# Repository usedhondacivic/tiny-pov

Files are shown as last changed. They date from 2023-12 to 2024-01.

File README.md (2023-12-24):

# tiny-pov



Work in progress, check back soon for more.

[Checkout the GUI](http://michael-crum.com/tiny-pov/) for a sneak peak.

Tiny-pov is a low cost, high performance, persistence of vision display built with the STM32G0.
This project is designed to explore cost effective and easily manufacturable mechatronic design.

I currently plan to use a STM32G0 to relay data from a SD Card directly into a string of APA102 LEDs. The arm will be inductively powered using custom coils.

See my first revision of the POV display here: https://github.com/usedhondacivic/ECE-4760-POV-Display

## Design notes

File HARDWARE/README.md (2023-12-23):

# Hardware

The Tiny-pov circuit boards were designed using [SKiDL](https://devbisme.github.io/skidl/), a python library for generating KiCAD schematics from python code. 
The SKiDL source code for the PCBs is found in `arm_board.py` and `motor_board.py`. The KiCAD symbol and schematic libraries for all components is included, so it should run without any hassle.

```cd HARDWARE && python3 arm_board.py```

For power delivery, I designed a custom 3D printed inductive power coupling inspired by electric toothbrushes. It uses a core of [ferrous 3D printer filament](https://proto-pasta.com/products/magnetic-iron-pla) to increase the efficiency of transformer.
You can find the design files on [OnShape](https://cad.onshape.com/documents/c43b3a736df7726a49e53755/w/ad83221bbc41dda85aa40265/e/0c03297652a8e1a4c52ec09d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).

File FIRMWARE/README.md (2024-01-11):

# FIRMWARE

Tiny-pov's firmware is written in baremetal C without use of any libraries (including the c stdlib!). The project includeds a custom SPI, SD, APA102, and FAT32 drivers.

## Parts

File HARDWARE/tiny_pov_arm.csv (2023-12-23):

Id | Designator | Footprint | Quantity | Designation | Supplier and ref
1 | TP1,TP2,TP3,TP4,TP5 | TestPoint_Pad | 5 | TestPoint
2 | J1 | PinHeader_1x02 | 1 | Conn_01x02_Socket
3 | D13,D10,D46,D20,D7,D54,D9,D3,D57,D41,D60,D59,D25,D35,D33,D15,D49,D55,D48,D6,D4,D61,D52,D23,D56,D64,D39,D30,D18,D24,D32,D16,D40,D37,D45,D5,D44,D50,D34,D14,D43,D51,D21,D2,D28,D8,D1,D11,D26,D63,D36,D19,D27,D53,D38,D62,D12,D22,D42,D47,D31,D17,D58,D29 | LED-APA102-2020 | 64 | APA102-2020
4 | C4,C3 | C_0603_hand_solder | 2 | 22 uF
5 | R2,R3,R4 | R_0603_hand_solder | 3 | 47k
6 | JP1 | SolderJumper | 1 | SolderJumper_2_Open
7 | R1 | R_0603_hand_solder | 1 | 10k
8 | U3 | STM32_SO_8N | 1 | STM32G030J6Mx
9 | BR1 | DBF_DIO | 1 | DBF310-13
10 | C1 | C_polarized_TH | 1 | ? uF
11 | J2 | microSD | 1 | SdHolder
12 | U1 | TSOT-23-6_HandSoldering | 1 | AP63203WU
13 | C2,C6 | C_0603_hand_solder | 2 | 100 nF
14 | U2 | SC-59_Handsoldering | 1 | AH1806W
15 | C5 | C_polarized_TH | 1 | 100 uF
16 | L1 | L_0603_hand_solder | 1 | 6.8uH

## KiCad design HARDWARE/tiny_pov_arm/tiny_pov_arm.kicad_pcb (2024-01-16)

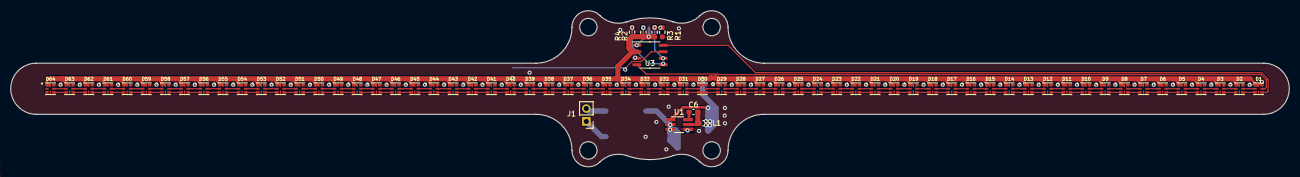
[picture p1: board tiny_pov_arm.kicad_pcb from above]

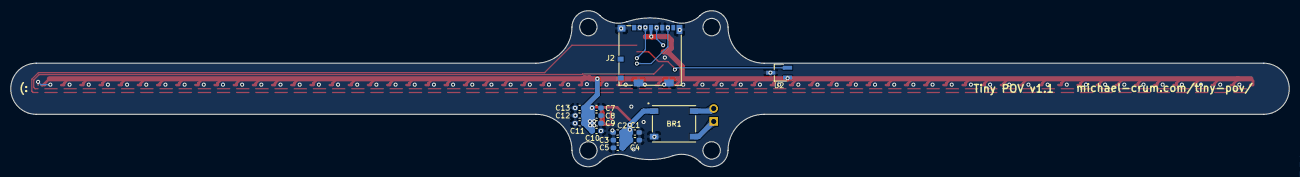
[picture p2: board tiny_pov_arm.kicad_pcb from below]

Board: 2 copper layers, 250.0 x 30.5 mm, 88 parts (15 on the bottom side), 140 nets.

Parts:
BR1: DBF310-13; DBF_DIO
C1, C2, C3, C4, C5, C7, C8, C9, C10, C11, C12, C13: 22 uF; C_0603_hand_solder
C6: 100 nF; C_0603_hand_solder
D1, D2, D3, D4, D5, D6, D7, D8, D9, D10, D11, D12, D13, D14, D15, D16, D17, D18, D19, D20, D21, D22, D23, D24, D25, D26, D27, D28, D29, D30, D31, D32, D33, D34, D35, D36, D37, D38, D39, D40, D41, D42, D43, D44, D45, D46, D47, D48, D49, D50, D51, D52, D53, D54, D55, D56, D57, D58, D59, D60, D61, D62, D63, D64: APA102-2020; LED_APA-102-2020-256-8
J1: Conn_01x02_Socket; PinHeader_1x02
J2: SdHolder; microSD
L1: 6.8uH; L_0603_hand_solder
R1: 10k; R_0603_hand_solder
R2, R3, R4: 47k; R_0603_hand_solder
U1: AP63203WU; TSOT-23-6_HandSoldering
U2: AH1806W; SC-59_Handsoldering
U3: STM32G030J6Mx; STM32_SO_8N

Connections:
BST: C6.1, U1.6
GND: BR1.3, C1.2, C2.2, C3.2, C4.2, C5.2, C7.2, C8.2, C9.2, C10.2, C11.2, C12.2, C13.2, D1.6, D2.6, D3.6, D4.6, D5.6, D6.6, D7.6, D8.6, D9.6, D10.6, D11.6, D12.6, D13.6, D14.6, D15.6, D16.6, D17.6, D18.6, D19.6, D20.6, D21.6, D22.6, D23.6, D24.6, D25.6, D26.6, D27.6, D28.6, D29.6, D30.6, D31.6, D32.6, D33.6, D34.6, D35.6, D36.6, D37.6, D38.6, D39.6, D40.6, D41.6, D42.6, D43.6, D44.6, D45.6, D46.6, D47.6, D48.6, D49.6, D50.6, D51.6, D52.6, D53.6, D54.6, D55.6, D56.6, D57.6, D58.6, D59.6, D60.6, D61.6, D62.6, D63.6, D64.6, J2.6, J2.11, R1.1, U1.4, U2.3, U3.3
HALL_DATA: U2.2, U3.7
LED_CLK: D1.5, U3.4
LED_DATA: D1.4, U3.8
SD_CS: J2.2, R1.2
SD_MISO: J2.7, R4.1, U3.5
SD_MOSI: J2.3, R3.1, U3.6
SD_SCK: J2.5, R2.1, U3.1
SW: C6.2, L1.1, U1.5
V_rect_plus: BR1.1, C1.1, C2.1, C3.1, C4.1, C5.1, U1.2, U1.3
Vac_a: BR1.4, J1.1
Vac_b: BR1.2, J1.2
Vdd: C7.1, C8.1, C9.1, C10.1, C11.1, C12.1, C13.1, D1.1, D2.1, D3.1, D4.1, D5.1, D6.1, D7.1, D8.1, D9.1, D10.1, D11.1, D12.1, D13.1, D14.1, D15.1, D16.1, D17.1, D18.1, D19.1, D20.1, D21.1, D22.1, D23.1, D24.1, D25.1, D26.1, D27.1, D28.1, D29.1, D30.1, D31.1, D32.1, D33.1, D34.1, D35.1, D36.1, D37.1, D38.1, D39.1, D40.1, D41.1, D42.1, D43.1, D44.1, D45.1, D46.1, D47.1, D48.1, D49.1, D50.1, D51.1, D52.1, D53.1, D54.1, D55.1, D56.1, D57.1, D58.1, D59.1, D60.1, D61.1, D62.1, D63.1, D64.1, J2.4, L1.2, R2.2, R3.2, R4.2, U1.1, U2.1, U3.2
apa_led_0_1_CK: D1.2, D2.5
apa_led_0_1_SD: D1.3, D2.4
apa_led_1_2_CK: D2.2, D3.5
apa_led_1_2_SD: D2.3, D3.4
apa_led_2_3_CK: D3.2, D4.5
apa_led_2_3_SD: D3.3, D4.4
apa_led_3_4_CK: D4.2, D5.5
apa_led_3_4_SD: D4.3, D5.4
apa_led_4_5_CK: D5.2, D6.5
apa_led_4_5_SD: D5.3, D6.4
apa_led_5_6_CK: D6.2, D7.5
apa_led_5_6_SD: D6.3, D7.4
apa_led_6_7_CK: D7.2, D8.5
apa_led_6_7_SD: D7.3, D8.4
apa_led_7_8_CK: D8.2, D9.5
apa_led_7_8_SD: D8.3, D9.4
apa_led_8_9_CK: D9.2, D10.5
apa_led_8_9_SD: D9.3, D10.4
apa_led_9_10_CK: D10.2, D11.5
apa_led_9_10_SD: D10.3, D11.4
apa_led_10_11_CK: D11.2, D12.5
apa_led_10_11_SD: D11.3, D12.4
apa_led_11_12_CK: D12.2, D13.5
apa_led_11_12_SD: D12.3, D13.4
apa_led_12_13_CK: D13.2, D14.5
apa_led_12_13_SD: D13.3, D14.4
apa_led_13_14_CK: D14.2, D15.5
apa_led_13_14_SD: D14.3, D15.4
apa_led_14_15_CK: D15.2, D16.5
apa_led_14_15_SD: D15.3, D16.4
apa_led_15_16_CK: D16.2, D17.5
apa_led_15_16_SD: D16.3, D17.4
apa_led_16_17_CK: D17.2, D18.5
apa_led_16_17_SD: D17.3, D18.4
apa_led_17_18_CK: D18.2, D19.5
apa_led_17_18_SD: D18.3, D19.4
apa_led_18_19_CK: D19.2, D20.5
apa_led_18_19_SD: D19.3, D20.4
apa_led_19_20_CK: D20.2, D21.5
apa_led_19_20_SD: D20.3, D21.4
apa_led_20_21_CK: D21.2, D22.5
apa_led_20_21_SD: D21.3, D22.4
apa_led_21_22_CK: D22.2, D23.5
apa_led_21_22_SD: D22.3, D23.4
apa_led_22_23_CK: D23.2, D24.5
apa_led_22_23_SD: D23.3, D24.4
apa_led_23_24_CK: D24.2, D25.5
apa_led_23_24_SD: D24.3, D25.4
apa_led_24_25_CK: D25.2, D26.5
apa_led_24_25_SD: D25.3, D26.4
apa_led_25_26_CK: D26.2, D27.5
apa_led_25_26_SD: D26.3, D27.4
apa_led_26_27_CK: D27.2, D28.5
apa_led_26_27_SD: D27.3, D28.4
apa_led_27_28_CK: D28.2, D29.5
apa_led_27_28_SD: D28.3, D29.4
apa_led_28_29_CK: D29.2, D30.5
apa_led_28_29_SD: D29.3, D30.4
apa_led_29_30_CK: D30.2, D31.5
apa_led_29_30_SD: D30.3, D31.4
apa_led_30_31_CK: D31.2, D32.5
apa_led_30_31_SD: D31.3, D32.4
apa_led_31_32_CK: D32.2, D33.5
apa_led_31_32_SD: D32.3, D33.4
apa_led_32_33_CK: D33.2, D34.5
apa_led_32_33_SD: D33.3, D34.4
apa_led_33_34_CK: D34.2, D35.5
apa_led_33_34_SD: D34.3, D35.4
apa_led_34_35_CK: D35.2, D36.5
apa_led_34_35_SD: D35.3, D36.4
apa_led_35_36_CK: D36.2, D37.5
apa_led_35_36_SD: D36.3, D37.4
apa_led_36_37_CK: D37.2, D38.5
apa_led_36_37_SD: D37.3, D38.4
apa_led_37_38_CK: D38.2, D39.5
apa_led_37_38_SD: D38.3, D39.4
apa_led_38_39_CK: D39.2, D40.5
apa_led_38_39_SD: D39.3, D40.4
apa_led_39_40_CK: D40.2, D41.5
apa_led_39_40_SD: D40.3, D41.4
apa_led_40_41_CK: D41.2, D42.5
apa_led_40_41_SD: D41.3, D42.4
apa_led_41_42_CK: D42.2, D43.5
apa_led_41_42_SD: D42.3, D43.4
apa_led_42_43_CK: D43.2, D44.5
apa_led_42_43_SD: D43.3, D44.4
apa_led_43_44_CK: D44.2, D45.5
apa_led_43_44_SD: D44.3, D45.4
apa_led_44_45_CK: D45.2, D46.5
apa_led_44_45_SD: D45.3, D46.4
apa_led_45_46_CK: D46.2, D47.5
apa_led_45_46_SD: D46.3, D47.4
apa_led_46_47_CK: D47.2, D48.5
apa_led_46_47_SD: D47.3, D48.4
apa_led_47_48_CK: D48.2, D49.5
apa_led_47_48_SD: D48.3, D49.4
apa_led_48_49_CK: D49.2, D50.5
apa_led_48_49_SD: D49.3, D50.4
apa_led_49_50_CK: D50.2, D51.5
apa_led_49_50_SD: D50.3, D51.4
apa_led_50_51_CK: D51.2, D52.5
apa_led_50_51_SD: D51.3, D52.4
apa_led_51_52_CK: D52.2, D53.5
apa_led_51_52_SD: D52.3, D53.4
apa_led_52_53_CK: D53.2, D54.5
apa_led_52_53_SD: D53.3, D54.4
apa_led_53_54_CK: D54.2, D55.5
apa_led_53_54_SD: D54.3, D55.4
apa_led_54_55_CK: D55.2, D56.5
apa_led_54_55_SD: D55.3, D56.4
apa_led_55_56_CK: D56.2, D57.5
apa_led_55_56_SD: D56.3, D57.4
apa_led_56_57_CK: D57.2, D58.5
apa_led_56_57_SD: D57.3, D58.4
apa_led_57_58_CK: D58.2, D59.5
apa_led_57_58_SD: D58.3, D59.4
apa_led_58_59_CK: D59.2, D60.5
apa_led_58_59_SD: D59.3, D60.4
apa_led_59_60_CK: D60.2, D61.5
apa_led_59_60_SD: D60.3, D61.4
apa_led_60_61_CK: D61.2, D62.5
apa_led_60_61_SD: D61.3, D62.4
apa_led_61_62_CK: D62.2, D63.5
apa_led_61_62_SD: D62.3, D63.4
apa_led_62_63_CK: D63.2, D64.5
apa_led_62_63_SD: D63.3, D64.4

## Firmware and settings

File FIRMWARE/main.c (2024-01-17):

/**
 * Author: Michael Crum
 * Date: 12/28/2023
 *
 * Entry point for Tiny POV
 *
 * https://github.com/usedhondacivic/tiny-pov
 * michael-crum.com/tiny-pov
 */

#include <stdbool.h>
#include <stdint.h>

#include "drivers/apa102/apa102.h"
#include "drivers/clock/clock.h"
#include "drivers/fat/fat.h"
#include "drivers/gpio/gpio.h"
#include "drivers/sd/sd.h"
#include "stm32g031xx.h"

static uint16_t sd_clk_pin = PIN('B', 8);
static uint16_t sd_mosi_pin = PIN('A', 10);
static uint16_t sd_miso_pin = PIN('A', 9);

static uint16_t apa102_clk_pin = PIN('A', 1);
static uint16_t apa102_data_pin = PIN('B', 5);

void apa102_gpio_map()
{
	// disable SWD
	gpio_set_mode(PIN('A', 14), GPIO_MODE_ANALOG);
	gpio_set_mode(PIN('A', 13), GPIO_MODE_ANALOG);
	gpio_set_PUPDR(PIN('A', 14), GPIO_NO_PULL);
	gpio_set_PUPDR(PIN('A', 13), GPIO_NO_PULL);

	gpio_set_mode(apa102_clk_pin, GPIO_MODE_AF);
	gpio_set_af(apa102_clk_pin, 0);
	gpio_set_highspeed(apa102_clk_pin);

	gpio_set_mode(apa102_data_pin, GPIO_MODE_AF);
	gpio_set_af(apa102_data_pin, 0);
	gpio_set_highspeed(apa102_data_pin);
}

int main(void)
{
	// Delay to allow reprogramming
	delay(3000);

	/* Configure GPIO */

	// SD Card SPI Mode
	gpio_set_mode(sd_clk_pin, GPIO_MODE_AF);
	gpio_set_af(sd_clk_pin, 1);
	gpio_set_highspeed(sd_clk_pin);

	SYSCFG->CFGR1 |= SYSCFG_CFGR1_PA11_RMP_Msk; // Enable A9
	SYSCFG->CFGR1 |= SYSCFG_CFGR1_PA12_RMP_Msk; // Enable A10
	gpio_set_mode(sd_mosi_pin, GPIO_MODE_AF);
	gpio_set_af(sd_mosi_pin, 0);
	gpio_set_highspeed(sd_mosi_pin);

	gpio_set_mode(sd_miso_pin, GPIO_MODE_AF);
	gpio_set_af(sd_miso_pin, 0b100u);
	gpio_set_highspeed(sd_miso_pin);

	/* Init peripherals */

	if (init_sd(SPI2)) {
		init_fat();
	}

	uint8_t pixel_buff_one[512] = { 0 };
	uint8_t pixel_buff_two[512] = { 0 };

	// tiny_pov.pov
	fat_open_file("TINY_POVPOV");
	// fat_read_file_block((uint8_t *)pixel_buff_one);

	init_apa102(SPI1);

	uint32_t bytes_remaining_total =
	  fat_read_file_block((uint8_t *)pixel_buff_one);
	uint32_t bytes_written_block = 0;
	while (bytes_remaining_total > 0) {
		bytes_remaining_total = fat_read_file_block((uint8_t *)pixel_buff_one);
		while (bytes_written_block <= 512 - 64 * 4 &&
			   bytes_remaining_total > 64 * 4) {
			apa102_gpio_map();
			apa102_write_strip((uint8_t *)pixel_buff_one);
		}
	}

	return 0;
}

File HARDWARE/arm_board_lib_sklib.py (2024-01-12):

from skidl import Pin, Part, Alias, SchLib, SKIDL, TEMPLATE

SKIDL_lib_version = '0.0.1'

arm_board_lib = SchLib(tool=SKIDL).add_parts(*[
        Part(**{ 'name':'Conn_01x02_Socket', 'dest':TEMPLATE, 'tool':SKIDL, 'datasheet':'~', '_name':'Conn_01x02_Socket', '_aliases':Alias({'Conn_01x02_Socket'}), '_match_pin_regex':False, 'description':'Generic connector, single row, 01x02, script generated', 'keywords':'connector', 'ref_prefix':'J', 'num_units':None, 'fplist':[''], 'do_erc':True, 'aliases':Alias({'Conn_01x02_Socket'}), 'pin':None, 'footprint':'tiny_pov_footprints:PinHeader_1x02', 'pins':[
            Pin(num='1',name='Pin_1',func=Pin.types.PASSIVE,do_erc=True),
            Pin(num='2',name='Pin_2',func=Pin.types.PASSIVE,do_erc=True)] }),
        Part(**{ 'name':'DBF310-13', 'dest':TEMPLATE, 'tool':SKIDL, 'datasheet':'DBF310-13', '_name':'DBF310-13', '_aliases':Alias({'DBF310-13'}), '_match_pin_regex':False, 'description':'', 'keywords':'DBF310-13', 'ref_prefix':'BR', 'num_units':None, 'fplist':['DBF_DIO'], 'do_erc':True, 'aliases':Alias({'DBF310-13'}), 'pin':None, 'footprint':'tiny_pov_footprints:DBF_DIO', 'pins':[
            Pin(num='1',name='V+',func=Pin.types.PWROUT,do_erc=True),
            Pin(num='2',name='Vac_b',func=Pin.types.PWRIN,do_erc=True),
            Pin(num='3',name='V-',func=Pin.types.PWROUT,do_erc=True),
            Pin(num='4',name='Vac_a',func=Pin.types.PWRIN,do_erc=True)] }),
        Part(**{ 'name':'C', 'dest':TEMPLATE, 'tool':SKIDL, 'datasheet':'~', '_name':'C', '_aliases':Alias({'C'}), '_match_pin_regex':False, 'description':'Unpolarized capacitor', 'keywords':'cap capacitor', 'ref_prefix':'C', 'num_units':None, 'fplist':[''], 'do_erc':True, 'aliases':Alias({'C'}), 'pin':None, 'footprint':'tiny_pov_footprints:C_0603_hand_solder', 'pins':[
            Pin(num='1',name='~',func=Pin.types.PASSIVE,do_erc=True),
            Pin(num='2',name='~',func=Pin.types.PASSIVE,do_erc=True)] }),
        Part(**{ 'name':'AP63203WU', 'dest':TEMPLATE, 'tool':SKIDL, 'datasheet':'https://www.diodes.com/assets/Datasheets/AP63200-AP63201-AP63203-AP63205.pdf', '_name':'AP63203WU', '_aliases':Alias({'AP63203WU'}), '_match_pin_regex':False, 'description':'2A, 1.1MHz Buck DC/DC Converter, fixed 3.3V output voltage, TSOT-23-6', 'keywords':'2A Buck DC/DC', 'ref_prefix':'U', 'num_units':None, 'fplist':['Package_TO_SOT_SMD:TSOT-23-6'], 'do_erc':True, 'aliases':Alias({'AP63203WU'}), 'pin':None, 'footprint':'tiny_pov_footprints:TSOT-23-6_HandSoldering', 'pins':[
            Pin(num='1',name='FB',func=Pin.types.INPUT,do_erc=True),
            Pin(num='2',name='EN',func=Pin.types.INPUT,do_erc=True),
            Pin(num='3',name='VIN',func=Pin.types.PWRIN,do_erc=True),
            Pin(num='4',name='GND',func=Pin.types.PWRIN,do_erc=True),
            Pin(num='5',name='SW',func=Pin.types.OUTPUT,do_erc=True),
            Pin(num='6',name='BST',func=Pin.types.PASSIVE,do_erc=True)] }),
        Part(**{ 'name':'L', 'dest':TEMPLATE, 'tool':SKIDL, 'datasheet':'~', '_name':'L', '_aliases':Alias({'L'}), '_match_pin_regex':False, 'description':'Inductor', 'keywords':'inductor choke coil reactor magnetic', 'ref_prefix':'L', 'num_units':None, 'fplist':[''], 'do_erc':True, 'aliases':Alias({'L'}), 'pin':None, 'footprint':'tiny_pov_footprints:L_0603_hand_solder', 'pins':[
            Pin(num='1',name='1',func=Pin.types.PASSIVE,do_erc=True),
            Pin(num='2',name='2',func=Pin.types.PASSIVE,do_erc=True)] }),
        Part(**{ 'name':'APA102-2020', 'dest':TEMPLATE, 'tool':SKIDL, 'datasheet':'http://www.led-color.com/upload/201604/APA102-2020%20SMD%20LED.pdf', '_name':'APA102-2020', '_aliases':Alias({'APA102-2020'}), '_match_pin_regex':False, 'description':'RGB LED with integrated controller', 'keywords':'RGB LED addressable 8bit pwm 5bit greyscale', 'ref_prefix':'D', 'num_units':None, 'fplist':['LED_SMD:LED-APA102-2020'], 'do_erc':True, 'aliases':Alias({'APA102-2020'}), 'pin':None, 'footprint':'tiny_pov_footprints:LED_APA-102-2020-256-8', 'pins':[
            Pin(num='1',name='VDD',func=Pin.types.PWRIN,do_erc=True),
            Pin(num='2',name='CKO',func=Pin.types.OUTPUT,do_erc=True),
            Pin(num='3',name='SDO',func=Pin.types.OUTPUT,do_erc=True),
            Pin(num='4',name='SDI',func=Pin.types.INPUT,do_erc=True),
            Pin(num='5',name='CKI',func=Pin.types.INPUT,do_erc=True),
            Pin(num='6',name='GND',func=Pin.types.PWRIN,do_erc=True)] }),
        Part(**{ 'name':'SdHolder', 'dest':TEMPLATE, 'tool':SKIDL, 'datasheet':'1040310811', '_name':'SdHolder', '_aliases':Alias({'SdHolder'}), '_match_pin_regex':False, 'description':'', 'keywords':'1040310811', 'ref_prefix':'J', 'num_units':None, 'fplist':['104031-0811_MOL'], 'do_erc':True, 'aliases':Alias({'SdHolder'}), 'pin':None, 'footprint':'tiny_pov_footprints:microSD', 'pins':[
            Pin(num='4',name='VDD',func=Pin.types.PWRIN,do_erc=True),
            Pin(num='1',name='DAT2',func=Pin.types.NOCONNECT,do_erc=True),
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

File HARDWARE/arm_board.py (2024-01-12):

# Author: Michael Crum
# Date: 11/14/23
# Circuit description for Tiny POV's arm circuit board. This is the part that rotates.
# Inductively powered from the board located in motor_board.py


from skidl import *

set_default_tool(KICAD7)

# TEMPLATES
jumper = Part(
    "tiny_pov_symbols",
    "SolderJumper_2_Open",
    dest=TEMPLATE,
    footprint="tiny_pov_footprints:SolderJumper",
)

test_point_pair = Part(
    "tiny_pov_symbols",
    "TestPoint_2Pole",
    dest=TEMPLATE,
    footprint="tiny_pov_footprints:PinHeader_1x02",
)

test_point = Part(
    "tiny_pov_symbols",
    "TestPoint",
    dest=TEMPLATE,
    footprint="tiny_pov_footprints:TestPoint_Pad",
)

R_0402 = Part(
    "tiny_pov_symbols",
    "R",
    dest=TEMPLATE,
    footprint="tiny_pov_footprints:R_0402_hand_solder",
)

C_0402 = Part(
    "tiny_pov_symbols",
    "C",
    dest=TEMPLATE,
    footprint="tiny_pov_footprints:C_0603_hand_solder",
)

R_0603 = Part(
    "tiny_pov_symbols",
    "R",
    dest=TEMPLATE,
    footprint="tiny_pov_footprints:R_0603_hand_solder",
)

C_0603 = Part(
    "tiny_pov_symbols",
    "C",
    dest=TEMPLATE,
    footprint="tiny_pov_footprints:C_0603_hand_solder",
)

C_TH = Part(
    "tiny_pov_symbols",
    "C_Polarized",
    dest=TEMPLATE,
    footprint="tiny_pov_footprints:C_polarized_TH",
)

L_0603 = Part(
    "tiny_pov_symbols",
    "L",
    dest=TEMPLATE,
    footprint="tiny_pov_footprints:L_0603_hand_solder",
)


# INTERFACES

power_supply_interface = Interface(
    Vac_a=Net("Vac_a", drive=POWER),
    Vac_b=Net("Vac_b", drive=POWER),
    Vdd=Net("Vdd", drive=POWER),
    GND=Net("GND", drive=POWER),
)

apa102_interface = Interface(
    CLK=Net("LED_CLK"),
    DATA=Net("LED_DATA"),
    Vdd=power_supply_interface.Vdd,
    GND=power_supply_interface.GND,
)

sd_card_interface = Interface(
    SCK=Net("SD_SCK"),
    MOSI=Net("SD_MOSI"),
    MISO=Net("SD_MISO"),
    CS=Net("SD_CS"),
    Vdd=power_supply_interface.Vdd,
    GND=power_supply_interface.GND,
)

hall_effect_interface = Interface(
    DATA=Net("HALL_DATA"),
    Vdd=power_supply_interface.Vdd,
    GND=power_supply_interface.GND,
)

stm32_interface = Interface(
    led_clk=apa102_interface.CLK,
    led_data=apa102_interface.DATA,
    sd_sck=sd_card_interface.SCK,
    sd_mosi=sd_card_interface.MOSI,
    sd_miso=sd_card_interface.MISO,
    hall_data=hall_effect_interface.DATA,
    Vdd=power_supply_interface.Vdd,
    GND=power_supply_interface.GND,
)


# SUBCIRCUITS
@subcircuit
def cap_combo(tag, val, num, a_net, b_net):
    for i in range(num):
        cap = C_0603(tag=f"{tag}-{i}", value=val)
        a_net & cap & b_net

# 3.3v converter: https://www.diodes.com/assets/Datasheets/AP63200-AP63201-AP63203-AP63205.pdf
# Full bridge rectifier: https://www.diodes.com/assets/Datasheets/DBF310.pdf
@subcircuit
def power_supply(interface):
    connector = Part(
        "tiny_pov_symbols",
        "Conn_01x02_Socket",
        footprint="tiny_pov_footprints:PinHeader_1x02",
        tag="pwr_supply",
    )

    rectifier = Part(
        "tiny_pov_symbols",
        "DBF310-13",
        footprint="tiny_pov_footprints:DBF_DIO",
        tag="rectifier",
    )


    # Coil connection
    connector["1"] & interface.Vac_a & rectifier["Vac_a"]
    connector["2"] & interface.Vac_b & rectifier["Vac_b"]

    # Rectifier IC
    rectifier["V-"] & interface.GND
    cap_combo("rect_smooth", "22 uF", 5, rectifier["V+"], rectifier["V-"])

    converter_3_3 = Part(
        "tiny_pov_symbols",
        "AP63203WU",
        footprint="tiny_pov_footprints:TSOT-23-6_HandSoldering",
        tag="3v3_converter",
    )

    # See data sheet for typical application circuit of the buck converter
    Net("V_rect_plus") & rectifier["V+"] & converter_3_3["VIN"] & converter_3_3["EN"]
    rectifier["V-"] & converter_3_3["GND"]
    bst_sw_cap = C_0603(value="100 nF", tag="3_3v_bst_sw_cap")
    output_cap = C_0603(value="22 uF", tag="3_3v_output_cap_a") | C_0603(
        value="22 uF", tag="3_3v_output_cap_b"
    )
    output_ind = L_0603(value="6.8uH", tag="3_3v_output_ind")
    Net("BST") & converter_3_3["BST"] & bst_sw_cap[1]
    Net("SW") & converter_3_3["SW"] & bst_sw_cap[2] & output_ind & interface.Vdd
    converter_3_3["FB"] & output_ind[2]
    interface.Vdd & output_cap & interface.GND


# APA102-2020: https://www.mouser.com/datasheet/2/737/APA102_2020_SMD_LED-2487271.pdf
@subcircuit
def apa102_led_strip(num_leds, interface):
    apa102_led = Part(
        "tiny_pov_symbols",
        "APA102-2020",
        dest=TEMPLATE,
        footprint="tiny_pov_footprints:LED_APA-102-2020-256-8",
    )
    # First LED connects to the STM32
    led = apa102_led(tag="apa_led_0")
    led["CKI"] & interface.CLK
    led["SDI"] & interface.DATA

    led["VDD"] += interface.Vdd
    led["GND"] += interface.GND

    # 100 uF cap to prevent brownouts
    cap_combo("surge_cap", "22 uF", 5, led["VDD"], led["GND"])

    # All other LEDs connect to the previous LED
    for i in range(num_leds - 1):
        new_led = apa102_led(tag=f"apa_led_{i + 1}")
        led["CKO"] & Net(f"apa_led_{i}_{i+1}_CK") & new_led["CKI"]
        led["SDO"] & Net(f"apa_led_{i}_{i+1}_SD") &  new_led["SDI"]
        new_led["VDD"] += interface.Vdd
        new_led["GND"] += interface.GND
        led = new_led

    led["CKO"] += NC
    led["SDO"] += NC


# SD Card Holder: https://tools.molex.com/pdm_docs/sd/5033981892_sd.pdf
@subcircuit
def sd_card(interface):
    sd_holder = Part(
        "tiny_pov_symbols",
        "SdHolder",
        footprint="tiny_pov_footprints:microSD",
        tag="sd_holder",
    )

    # SD card is the only device on the bus, pull CS low
    (
        interface.GND
        & R_0603(value="10k", tag="SD_CS_PULLDOWN")
        & interface.CS
        & sd_holder["CS"]
    )

    # Each data line with a pull up resistor
    (
        sd_holder["SCK"]
        & tee(R_0603(value="47k", tag="SD_SCK_PULLUP") & interface.Vdd)
        & interface.SCK
    )
    (
        sd_holder["MOSI"]
        & tee(R_0603(value="47k", tag="SD_MOSI_PULLUP") & interface.Vdd)
        & interface.MOSI
    )
    (
        sd_holder["MISO"]
        & tee(R_0603(value="47k", tag="SD_MISO_PULLUP") & interface.Vdd)
        & interface.MISO
    )

    # Power and ground
    sd_holder["VDD"] & interface.Vdd
    sd_holder["GND"] & interface.GND & sd_holder[11]


# Hall effect sensor: https://www.diodes.com/assets/Datasheets/AH1806.pdf
@subcircuit
def hall_effect(interface):
    hall = Part(
        "tiny_pov_symbols",
        "AH1806W",
        footprint="tiny_pov_footprints:SC-59_Handsoldering",
        tag="hall_effect",
    )
    hall["VDD"] += interface.Vdd
    hall["GND"] += interface.GND
    hall["OUTPUT"] += interface.DATA
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

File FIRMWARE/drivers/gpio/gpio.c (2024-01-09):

/**
 * Author: Michael Crum
 * Date: 12/25/2023
 *
 * Hardware abstraction layer for the STM32G031 MCU
 *
 * MCU reference manual:
 * https://www.st.com/resource/en/reference_manual/rm0444-stm32g0x1-advanced-armbased-32bit-mcus-stmicroelectronics.pdf
 * Excerpts from:
 * https://github.com/cpq/bare-metal-programming-guide
 */

#include <stdbool.h>
#include <stm32g031xx.h>

#include "gpio.h"

void gpio_set_mode(uint16_t pin, uint8_t mode)
{
	GPIO_TypeDef *gpio = GPIO(PINBANK(pin)); // GPIO bank
	int n = PINNO(pin);						 // Pin number
	RCC->IOPENR |= BIT(PINBANK(pin));		 // Enable GPIO clock
	gpio->MODER &= ~(3U << (n * 2));		 // Clear existing setting
	gpio->MODER |= (mode & 3U) << (n * 2);	 // Set new mode
}

void gpio_set_PUPDR(uint16_t pin, uint8_t mode)
{
	GPIO_TypeDef *gpio = GPIO(PINBANK(pin)); // GPIO bank
	int n = PINNO(pin);						 // Pin number
	RCC->IOPENR |= BIT(PINBANK(pin));		 // Enable GPIO clock
	gpio->PUPDR &= ~(3U << (n * 2));		 // Clear existing setting
	gpio->PUPDR |= (mode & 3U) << (n * 2);	 // Set new mode
}

void gpio_set_af(uint16_t pin, uint8_t af_num)
{
	GPIO_TypeDef *gpio = GPIO(PINBANK(pin)); // GPIO bank
	int n = PINNO(pin);						 // Pin number
	gpio->AFR[n >> 3] &= ~(15UL << ((n & 7) * 4));
	gpio->AFR[n >> 3] |= ((uint32_t)af_num) << ((n & 7) * 4);
}

void gpio_write(uint16_t pin, bool val)
{
	GPIO_TypeDef *gpio = GPIO(PINBANK(pin));
	gpio->BSRR = (1U << PINNO(pin)) << (val ? 0 : 16);
}

void gpio_set_highspeed(uint16_t pin)
{
	GPIO_TypeDef *gpio = GPIO(PINBANK(pin));
	int n = PINNO(pin);					 // Pin number
	gpio->OSPEEDR &= ~(3U << (n * 2));	 // Clear existing setting
	gpio->OSPEEDR |= (0b11u) << (n * 2); // Set new mode
}

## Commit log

2023-11-09 Broke SPI driver out into library
    [uart.cpp]
2023-11-13 Started SKiDL board implementation
2023-11-14 Added footprints, symbols, more work on SKiDL board
2023-11-14 Completed V1 of SKiDL schematic
    [tiny_pov_arm.kicad_pcb, tiny_pov_arm.kicad_sch]
2023-11-14 Completed V1 arm board layout
    [tiny_pov_arm.kicad_pcb]
2023-11-21 Start STM32 development
2023-12-23 Iterated board layout
    [tiny_pov_arm.kicad_pcb]
2023-12-23 v1 board ordered
    [tiny_pov_arm-B_Cu.gbr, tiny_pov_arm-B_Mask.gbr, tiny_pov_arm-B_Paste.gbr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]
2023-12-23 Fix typos in readme
    [tiny_pov_arm.kicad_pcb]
2023-12-24 STM32G0 blinking
2023-12-29 apa102 driver working
2024-01-02 Changed apa102 to correct footprint, changed STM32 pinout to allow for SPI
    [tiny_pov_arm.kicad_pcb]
2024-01-05 apa102 over spi working
2024-01-05 Cleaned up apa102 driver
2024-01-08 Moved SPI to seperate driver
2024-01-11 FAT driver can now read root directory
2024-01-11 Work on finding files in FAT driver
2024-01-12 Arm board v1.1
    [tiny_pov_arm.kicad_pcb]
2024-01-16 Gerbers for v1.1 order
    [tiny_pov_arm-B_Cu.gbr, tiny_pov_arm-B_Mask.gbr, tiny_pov_arm-B_Paste.gbr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]
